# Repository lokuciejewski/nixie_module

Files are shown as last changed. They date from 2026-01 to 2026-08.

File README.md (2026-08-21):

# Small module for standalone I2C control over Nixie Tube

This module is a small, low cost controller board for a nixie `z5740m` tube (and some compatible tubes, like `z5730`). It is based on the `ch32v003` microcontroller and is using a i2c protocol for communication with external host.
The board needs both VCC (either 3.3V or 5V) and the voltage for the tube (usually around 170V DC).

V1 module

The module works in tandem with the [controller board](https://github.com/lokuciejewski/nixie_controller):

V1 of the board with modules

## Building

Prerequisites are:

- GCC or other C compiler
- [ch32fun](https://github.com/cnlohr/ch32fun) stack
- GNU make

Clone the `ch32fun` into the root folder of this project. Then run `make build` to compile the firmware.

## Programming

A ch32v003 programmer is required (for example the WCH-Link-E). Connect the programmer to the VCC, GND and SWIO pins and run `make flash`.

## Communication over i2c bus

By default, this module starts with the address `0x40` (0x20 << 1, see [main.c](./main.c)).
After that, a new address can be written over the i2c which will be saved into the flash and the module will subsequently answer on the new address.

Communication over the i2c bus is a standard way, except there is no auto increment of the register when reading.

### I2c registers

This device contains the following i2c registers:

- I2cReg_Address -> `0x00` - used to set a new i2c address for the device
- I2cReg_NixieValue -> `0x01` - read or write the current digit that should be displayed
- I2cReg_HvValueLowByte -> `0x02` - read the high byte of the current High Voltage reading
- I2cReg_HvValueHighByte -> `0x03` - read the low byte of the current High Voltage reading
- I2cReg_NixiePwmValue -> `0x04` - read or write the new PWM brightness value (0-100)
- I2cReg_NixieBrightnessCompensation -> `0x05` - turn on or off brightness compensation (this reduces the brightness of the main digit if the commma is on)

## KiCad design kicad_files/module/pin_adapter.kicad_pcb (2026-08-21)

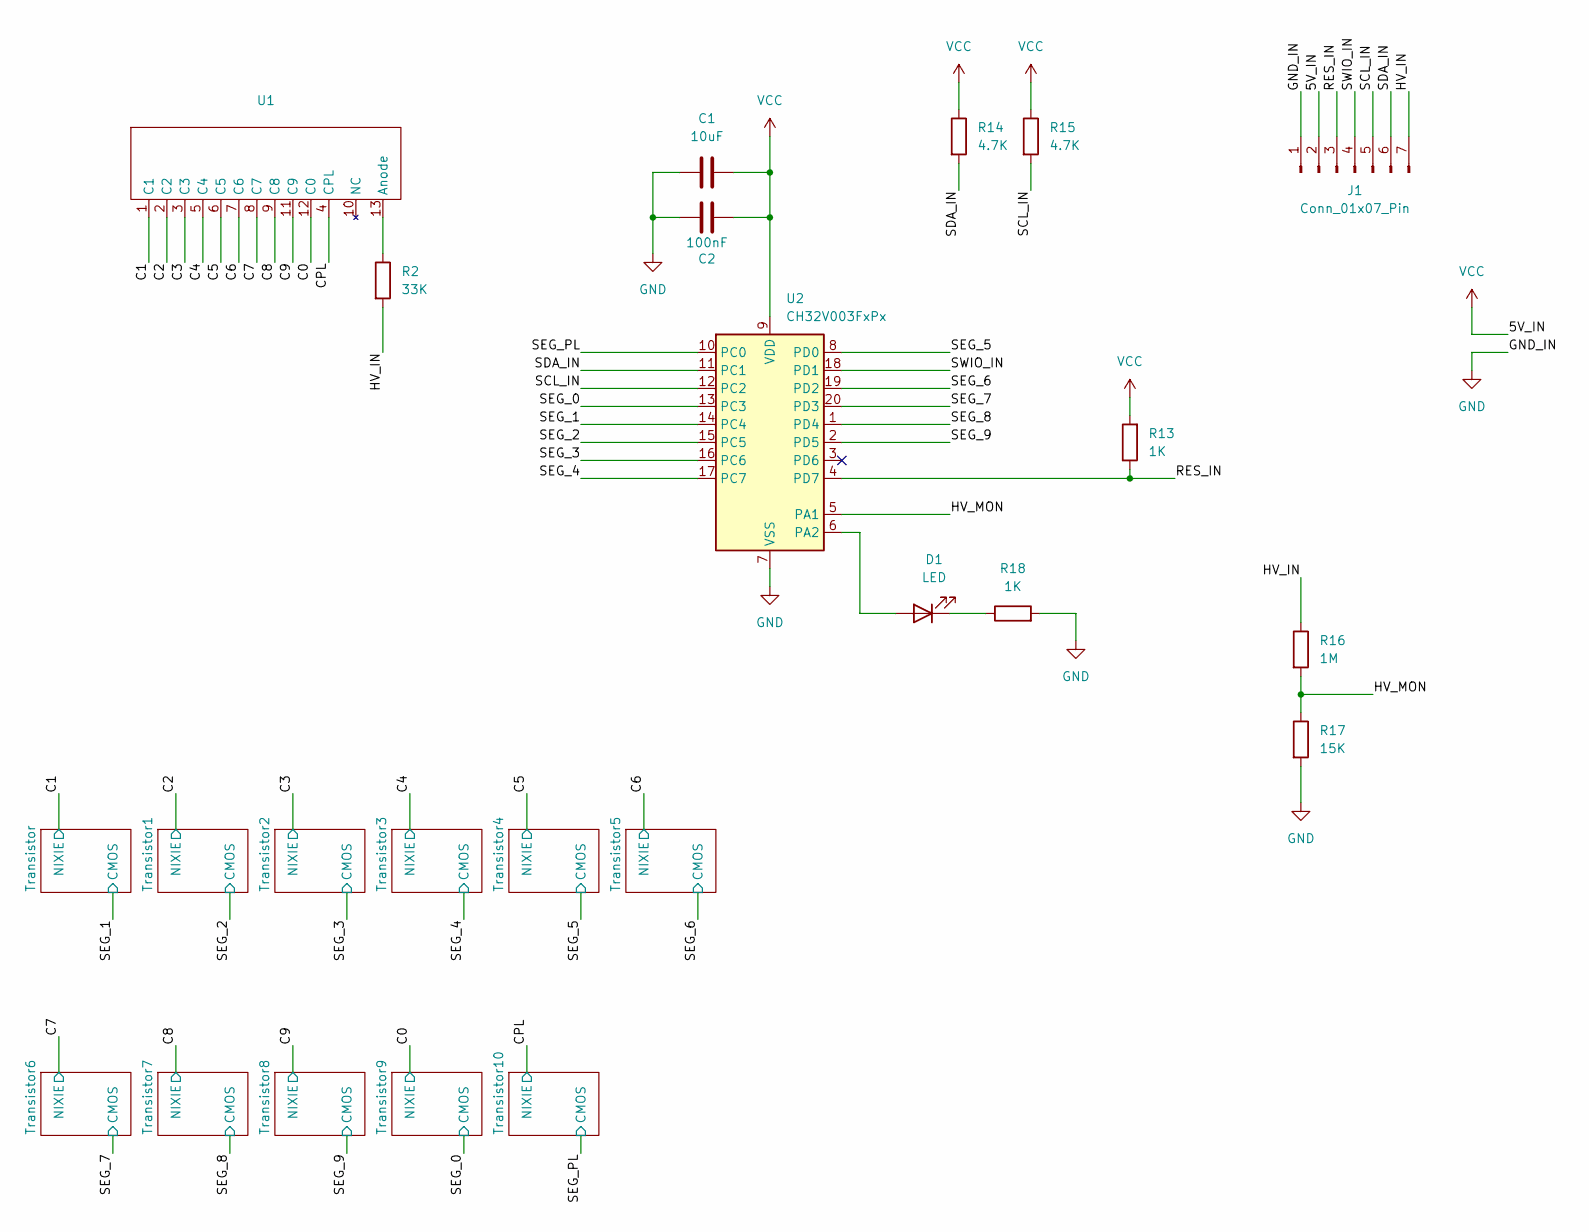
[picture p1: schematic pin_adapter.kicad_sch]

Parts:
C1: 10uF; C_0603_1608Metric_Pad1.08x0.95mm_HandSolder
C2: 100nF; C_0603_1608Metric_Pad1.08x0.95mm_HandSolder
D1: LED; LED_0603_1608Metric_Pad1.05x0.95mm_HandSolder
J1: Conn_01x07_Pin; PinHeader_1x07_P2.54mm_Vertical
R2: 33K; R_1206_3216Metric_Pad1.30x1.75mm_HandSolder
R13, R18: 1K; R_0603_1608Metric_Pad0.98x0.95mm_HandSolder
R14, R15: 4.7K; R_0603_1608Metric_Pad0.98x0.95mm_HandSolder
R16: 1M; R_0603_1608Metric_Pad0.98x0.95mm_HandSolder
R17: 15K; R_0603_1608Metric_Pad0.98x0.95mm_HandSolder
U1: z5740m
U2: CH32V003FxPx; TSSOP-20_4.4x6.5mm_P0.65mm

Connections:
/C0: U1.12 (C0); also elsewhere on the board
/C1: U1.1 (C1); also elsewhere on the board
/C2: U1.2 (C2); also elsewhere on the board
/C3: U1.3 (C3); also elsewhere on the board
/C4: U1.5 (C4); also elsewhere on the board
/C5: U1.6 (C5); also elsewhere on the board
/C6: U1.7 (C6); also elsewhere on the board
/C7: U1.8 (C7); also elsewhere on the board
/C8: U1.9 (C8); also elsewhere on the board
/C9: U1.11 (C9); also elsewhere on the board
/CPL: U1.4 (CPL); also elsewhere on the board
/HV_IN: J1.7, R2.2, R16.1
/HV_MON: R16.2, R17.1, U2.5 (PA1)
/RES_IN: J1.3, R13.1, U2.4 (PD7)
/SCL_IN: J1.5, R15.2, U2.12 (PC2)
/SDA_IN: J1.6, R14.2, U2.11 (PC1)
/SEG_0: U2.13 (PC3); also elsewhere on the board
/SEG_1: U2.14 (PC4); also elsewhere on the board
/SEG_2: U2.15 (PC5); also elsewhere on the board
/SEG_3: U2.16 (PC6); also elsewhere on the board
/SEG_4: U2.17 (PC7); also elsewhere on the board
/SEG_5: U2.8 (PD0); also elsewhere on the board
/SEG_6: U2.19 (PD2); also elsewhere on the board
/SEG_7: U2.20 (PD3); also elsewhere on the board
/SEG_8: U2.1 (PD4); also elsewhere on the board
/SEG_9: U2.2 (PD5); also elsewhere on the board
/SEG_PL: U2.10 (PC0); also elsewhere on the board
/SWIO_IN: J1.4, U2.18 (PD1)
GND: C1.1, C2.2, J1.1, R17.2, R18.2, U2.7 (VSS); also elsewhere on the board
unnamed: D1.2 (A), U2.6 (PA2)
unnamed: D1.1 (K), R18.1
unnamed: R2.1, U1.13 (Anode)
VCC: C1.2, C2.1, J1.2, R13.2, R14.1, R15.1, U2.9 (VDD)

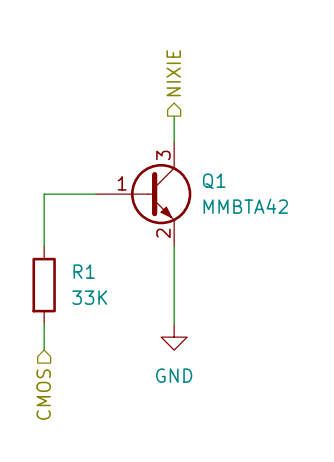
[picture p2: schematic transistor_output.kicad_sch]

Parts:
Q1: MMBTA42; SOT-23
R1: 33K; R_0603_1608Metric_Pad0.98x0.95mm_HandSolder

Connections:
/C1: Q1.3 (C); also elsewhere on the board
/SEG_1: R1.2; also elsewhere on the board
GND: Q1.2 (E); also elsewhere on the board
unnamed: Q1.1 (B), R1.1

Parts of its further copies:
Q2, Q3, Q4, Q5, Q6, Q7, Q8, Q9, Q10, Q11: MMBTA42; SOT-23
R3, R4, R5, R6, R7, R8, R9, R10, R11, R12: 33K; R_0603_1608Metric_Pad0.98x0.95mm_HandSolder

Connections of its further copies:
/C0: Q10.3 (C); also elsewhere on the board
/C2: Q2.3 (C); also elsewhere on the board
/C3: Q3.3 (C); also elsewhere on the board
/C4: Q4.3 (C); also elsewhere on the board
/C5: Q5.3 (C); also elsewhere on the board
/C6: Q6.3 (C); also elsewhere on the board
/C7: Q7.3 (C); also elsewhere on the board
/C8: Q8.3 (C); also elsewhere on the board
/C9: Q9.3 (C); also elsewhere on the board
/CPL: Q11.3 (C); also elsewhere on the board
/SEG_0: R11.2; also elsewhere on the board
/SEG_2: R3.2; also elsewhere on the board
/SEG_3: R4.2; also elsewhere on the board
/SEG_4: R5.2; also elsewhere on the board
/SEG_5: R6.2; also elsewhere on the board
/SEG_6: R7.2; also elsewhere on the board
/SEG_7: R8.2; also elsewhere on the board
/SEG_8: R9.2; also elsewhere on the board
/SEG_9: R10.2; also elsewhere on the board
/SEG_PL: R12.2; also elsewhere on the board
GND: Q2.2 (E), Q3.2 (E), Q4.2 (E), Q5.2 (E), Q6.2 (E), Q7.2 (E), Q8.2 (E), Q9.2 (E), Q10.2 (E), Q11.2 (E); also elsewhere on the board
unnamed: Q2.1 (B), R3.1
unnamed: Q3.1 (B), R4.1
unnamed: Q4.1 (B), R5.1
unnamed: Q5.1 (B), R6.1
unnamed: Q6.1 (B), R7.1
unnamed: Q7.1 (B), R8.1
unnamed: Q8.1 (B), R9.1
unnamed: Q9.1 (B), R10.1
unnamed: Q10.1 (B), R11.1
unnamed: Q11.1 (B), R12.1

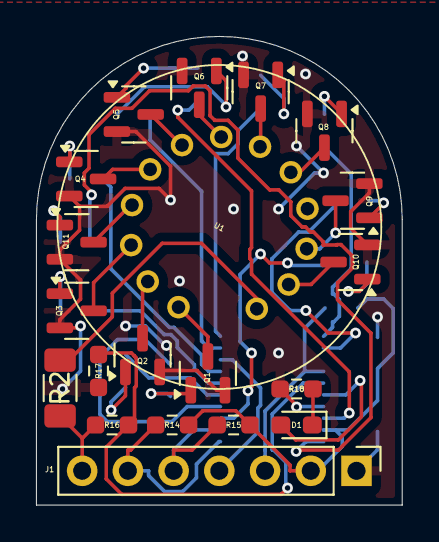
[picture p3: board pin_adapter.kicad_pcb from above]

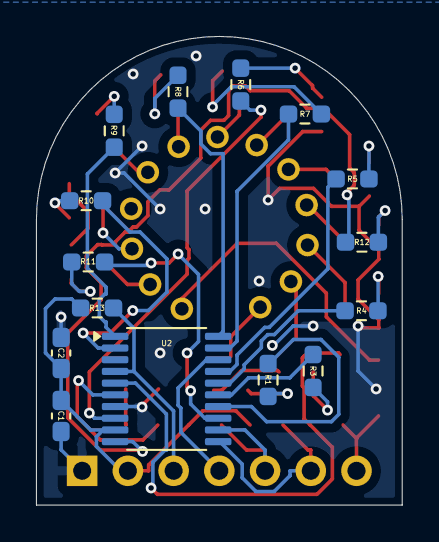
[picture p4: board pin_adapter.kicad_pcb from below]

Board: 2 copper layers, 20.3 x 26.0 mm, 35 parts (15 on the bottom side), 44 nets.

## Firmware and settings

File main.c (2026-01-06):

#include "ch32fun/ch32fun/ch32fun.h"
#include "i2c_slave.h"
#include "nixie.h"

#define LED_PIN PA2

typedef enum : uint8_t {
    I2cReg_Address = 0,
    I2cReg_NixieValue,
    I2cReg_HvValueLowByte,
    I2cReg_HvValueHighByte,
    I2cReg_NixiePwmValue,
    I2cReg_NixieBrightnessCompensation,
    I2cReg_Size,
} I2cRegisters_e;

#define I2C_DEFAULT_ADDRESS (uint8_t)(0x20)

#define SYSTEM_VOLTAGE_MV 3300U
#define HV_UPPER_LIMIT_MV 3300U
#define HV_LOWER_LIMIT_MV 2700U
#define HV_UPPER_LIMIT ((1000 * HV_UPPER_LIMIT_MV) / SYSTEM_VOLTAGE_MV)
#define HV_LOWER_LIMIT ((1000 * HV_LOWER_LIMIT_MV) / SYSTEM_VOLTAGE_MV)

#define DEFAULT_LOOP_TIME_US 450U

volatile uint8_t i2c_registers[I2cReg_Size - 1] = {0x00};
bool change_address = false;
uint8_t new_i2c_address = 0x00;
uint8_t* i2c_address = (uint8_t*)0x08003700;

bool unsafe_hv = true;

void onWrite(uint8_t reg, uint8_t length) {
    switch ((I2cRegisters_e)reg) {
    case I2cReg_Address:
        if (*i2c_address != i2c_registers[I2cReg_Address]) {
            change_address = true;
            new_i2c_address = i2c_registers[I2cReg_Address];
        }
        break;

    case I2cReg_NixieValue:
        if (!unsafe_hv) {
            if (i2c_registers[reg] != 0xff) {
                Nixie_TurnOn(Nixie_FromUINT8(i2c_registers[reg] & 0b1111));
                if ((i2c_registers[I2cReg_NixieValue] & 0b10000000) != 0) {
                    Nixie_CommaOn();
                } else {
                    Nixie_CommaOff();
                }
                break;
            } else {
                Nixie_TurnOff();
            }
            i2c_registers[I2cReg_NixieValue] = Nixie_GetCurrentSeg();
        }
        break;
    case I2cReg_NixiePwmValue:
        Nixie_PWM_SetDutyCycle(i2c_registers[I2cReg_NixiePwmValue]);
        break;
    case I2cReg_NixieBrightnessCompensation:
        // TODO: implement
        break;

    default:
        break;
    }
}

void onRead(uint8_t reg) {}

static void unlockFlash(void) {
    FLASH->KEYR = FLASH_KEY1;
    FLASH->KEYR = FLASH_KEY2;
    while (FLASH->STATR & FLASH_STATR_BSY) {
    }
}

static void unlockProgramming(void) {
    FLASH->MODEKEYR = FLASH_KEY1;
    FLASH->MODEKEYR = FLASH_KEY2;
    while (FLASH->STATR & FLASH_STATR_BSY) {
    }
}

static void changeAddress(void) {
    unlockFlash();
    unlockProgramming();
    // Erase page
    FLASH->CTLR = CR_PAGE_ER;
    FLASH->ADDR = (intptr_t)i2c_address;
    FLASH->CTLR = CR_STRT_Set | CR_PAGE_ER;
    // Page erase takes about 3ms
    while (FLASH->STATR & FLASH_STATR_BSY) {
    }

    if (*i2c_address != 0xff) {
        while (1) // Flash erase didn't work
        {
        }
    }
    // Clear buffer and prepare for flashing
    FLASH->CTLR = CR_PAGE_PG;
    FLASH->CTLR = CR_BUF_RST | CR_PAGE_PG;
    FLASH->ADDR = (intptr_t)i2c_address;
    while (FLASH->STATR & FLASH_STATR_BSY) // Not really needed
    {
    }
    // Write to the memory
    for (uint8_t i = 0; i < 16; i++) {
        ((uint32_t*)i2c_address)[i] = (uint32_t)new_i2c_address;
        FLASH->CTLR = CR_PAGE_PG | FLASH_CTLR_BUF_LOAD; // Load the buffer.
        while (FLASH->STATR &
               FLASH_STATR_BSY) // Only needed if running from RAM.
        {
        }
    }

    // Actually write the flash out. (Takes about 3ms)
    FLASH->CTLR = CR_PAGE_PG | CR_STRT_Set;

    while (FLASH->STATR & FLASH_STATR_BSY) {
    }

    if (*i2c_address != new_i2c_address) {
        while (1) // Flash write didn't work
        {
        }
    }
    // Perform software reset
    PFIC->SCTLR |= 0x80000000;
}

int main() {
    SystemInit();
    funGpioInitAll();
    funAnalogInit();

    // Initialise led
    funPinMode(LED_PIN, GPIO_Speed_10MHz | GPIO_CNF_OUT_PP);
    // Initialise adc - high voltage monitoring
    funPinMode(PA1, GPIO_CFGLR_IN_ANALOG);

    funDigitalWrite(LED_PIN, FUN_HIGH);
    Nixie_Init();

    // Initialize I2C slave
    funPinMode(PC1, GPIO_CFGLR_OUT_10Mhz_AF_OD); // SDA
    funPinMode(PC2, GPIO_CFGLR_OUT_10Mhz_AF_OD); // SCL

    if (*i2c_address == 0xff) {
        // Address not set yet, use I2C_DEFAULT_ADDRESS
        SetupI2CSlave(I2C_DEFAULT_ADDRESS, i2c_registers, sizeof(i2c_registers),
                      onWrite, onRead, false);
        i2c_registers[I2cReg_Address] = I2C_DEFAULT_ADDRESS;
    } else {
        SetupI2CSlave(*i2c_address, i2c_registers, sizeof(i2c_registers),
                      onWrite, onRead, false);
        i2c_registers[I2cReg_Address] = *i2c_address;
    }

    i2c_registers[I2cReg_NixieValue] = 0xff; // Nixie off

    Delay_Ms(10); // Just to make sure the led blinks
    funDigitalWrite(LED_PIN, FUN_LOW);

    uint16_t hv_value = 0;

    while (1) {
        if (change_address) {
            funDigitalWrite(LED_PIN, FUN_HIGH);
            changeAddress();
        }
        hv_value = (uint16_t)funAnalogRead(ANALOG_1);
        i2c_registers[I2cReg_HvValueLowByte] = (uint8_t)(hv_value & 0xff);
        i2c_registers[I2cReg_HvValueHighByte] = (uint8_t)(hv_value >> 8);
        // unsafe_hv = hv_value > HV_UPPER_LIMIT;
        unsafe_hv =
            false; // TODO: replace 20k resistor with 15k to measure voltage
        if (unsafe_hv) {
            Nixie_CommaOff();
            Nixie_TurnOff();
            funDigitalWrite(LED_PIN, FUN_HIGH);
        } else {
            funDigitalWrite(LED_PIN, FUN_LOW);
            Nixie_PWM_RefreshEvery500us();
        }
        Delay_Us(DEFAULT_LOOP_TIME_US);
    }
}

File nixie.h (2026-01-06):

#pragma once
#include "ch32fun/ch32fun/ch32fun.h"
#include "stdbool.h"
#include "stdint.h"

typedef enum {
    NIXIE_SEG_0 = PC3,
    NIXIE_SEG_1 = PC4,
    NIXIE_SEG_2 = PC5,
    NIXIE_SEG_3 = PC6,
    NIXIE_SEG_4 = PC7,
    NIXIE_SEG_5 = PD0,
    NIXIE_SEG_6 = PD2,
    NIXIE_SEG_7 = PD3,
    NIXIE_SEG_8 = PD4,
    NIXIE_SEG_9 = PD5,
    NIXIE_SEG_PL = PC0,
    NIXIE_SEG_NO_SEG = 0xff,
} NixieSegment;

void Nixie_Init(void);
/// Should be called periodically for software PWM
void Nixie_PWM_RefreshEvery500us(void);
/// Value needs to be between 0 and 20 for 0% to 100%
void Nixie_PWM_SetDutyCycle(uint8_t new_duty_cycle);
void Nixie_DisplayRefresh(uint16_t delay_ms);
void Nixie_EnableCommaBrightnessCompensation(void);
void Nixie_DisableCommaBrightnessCompensation(void);

NixieSegment Nixie_GetCurrentSeg(void);
bool Nixie_IsCommaOn(void);
uint8_t Nixie_ToUINT8(NixieSegment seg);
NixieSegment Nixie_FromUINT8(uint8_t seg);

void Nixie_TurnOn(NixieSegment seg);
void Nixie_TurnOff(void);
void Nixie_CommaOn(void);
void Nixie_CommaOff(void);

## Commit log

2025-08-25 sample 1 changes
2025-12-30 added clang-format, added soft PWM (WIP), minor fixes
    [main.c, nixie.c, nixie.h]
2025-12-30 added missing files, added PWM control + PWM compensation on comma on
    [main.c, nixie.c, nixie.h]
2025-12-30 increased PWM resolution to 0.5ms
2026-01-06 fixed NIXIE_SEG_NO_SEG being equal to NIXIE_SEG_0, removed refresh trigger from i2c
    [main.c, nixie.c, nixie.h]
2026-01-06 fixed i2c regs size, changed pwm_value to 32-bit
    [main.c, nixie.c]
2026-01-09 added turning off all numeric segments to prevent glitches
    [nixie.c]
2026-08-21 added kicad files
    [pin_adapter.kicad_pcb, pin_adapter.kicad_sch, transistor_output.kicad_sch]
